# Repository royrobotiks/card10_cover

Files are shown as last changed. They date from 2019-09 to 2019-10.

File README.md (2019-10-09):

# A cover generator for the CARD10 badge!
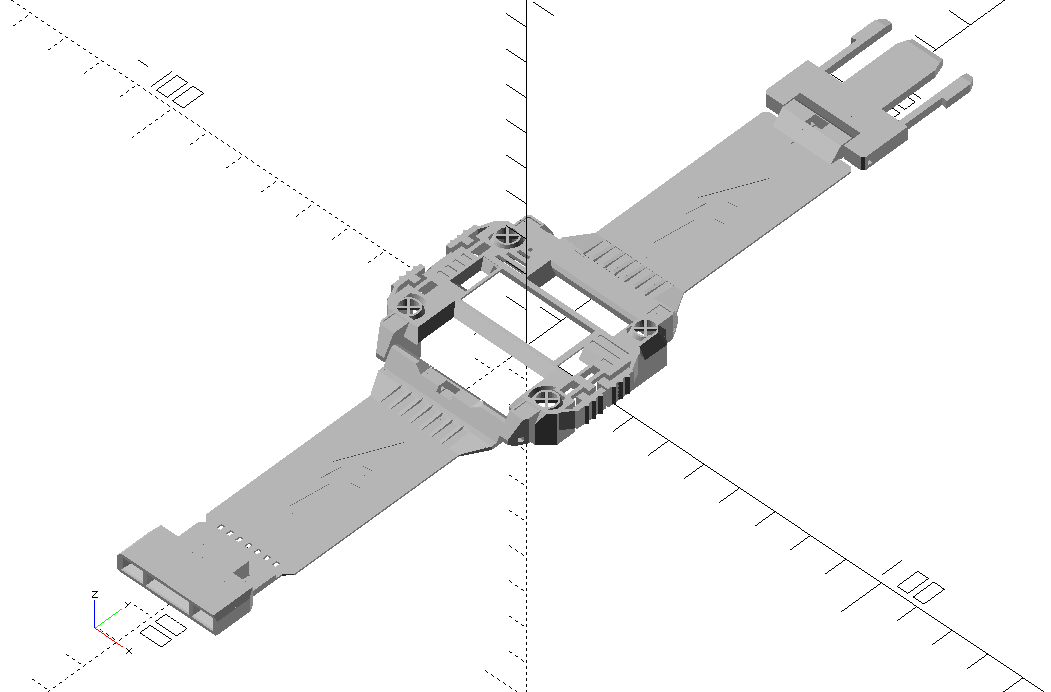
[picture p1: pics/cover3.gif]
different covers
 
          
## Features
- interactive web interface available at https://card10-cover.0x1b.de/index.php (thx to segal!)
- more variations possible than you'll ever need!!!
- buttons become much more usable as they get a bigger surface
- the cover can be clipped onto the badge - there are no tools required to change the cover
- you can add a piece of clear plastic (e.g. cutout from a cheese packaging) as display protection 
- the model has no overhangs, thus it is very easy to print (except if you turn side led's on)
- you can turn off the randomization and generate exactly the cover that YOU want!

## How to use
- open this code in openSCAD (download from https://www.openscad.org/)
- specify whether you want a model with wristband or without (line 82) / the option
          with wristband also adds the wristband mounts (32 mm) to the watch cover
- if you want to print a wristband, specify the sircumference of your wrist in line 107
- specify from line 69 on which parts you want to generate 
- select in line 68 if you want to have the parts oriented ready for print or in the way they will be
          assembled later
- [optional]: adjust settings below in the section 'CUSTOMIZE YOUR COVER BY ADJUSTING VALUES BELOW:'
- hit the render button in openSCAD (the button above the code with the hourglass & the cube)
- hit the .stl export button right next to the render button
- print your .stl model!

## Printing instructions

- print upside down without support out of PLA
- recommended slicer settings: 
   0.2mm layer height
   0.4mm wall thickness / 1 wall
   100% infill 
   0.4mm extruder

## Assembly instructions

- clean up the print with a small utility knife
- [optional]: cut a 14mm x 30mm piece of clear plastic as display protection (e.g. from a pet-bottle) 
                      and place it inside the display cutout 
- If you printed a wristband: Glue FClip on the end of the bottom wristband (e.g. with superglue)
- connect MClip with the top wristband (with a paper clip as axle)
- connect both wristbands to the cover (with paper clips as axles)
- if you printed a bottom: Unscrew the four screws on the bottom of the Card10, 
          remove the stainless steel electrodes, add the bottom piece, add the electrodes, 
          add the screws again.
- clip the cover onto your card10 badge
- print another cover for your friends

## Wristband assembly

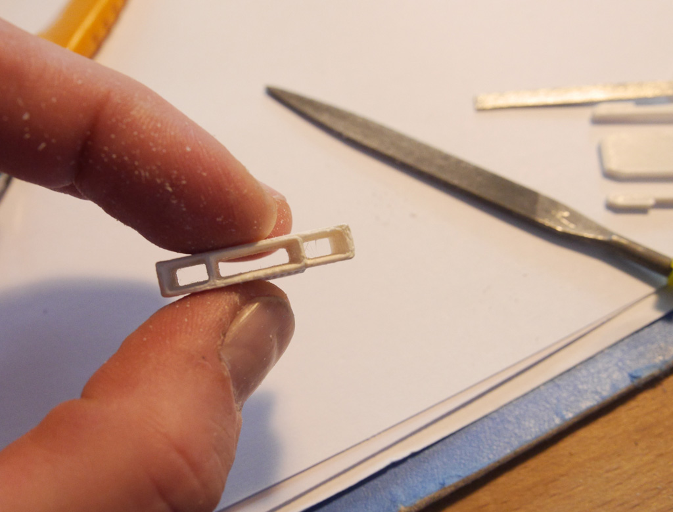
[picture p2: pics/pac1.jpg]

Step 1: Clean up the inside of FClip with a small file.

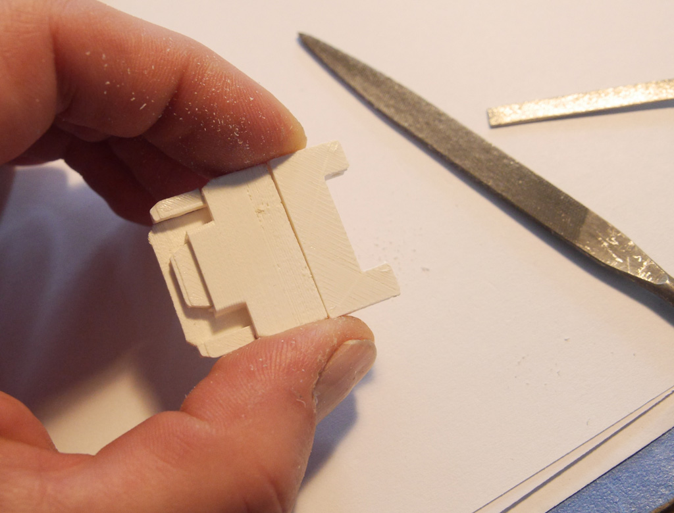
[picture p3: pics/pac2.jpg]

Step 2: Make sure that MClip fits smooth into FClip.

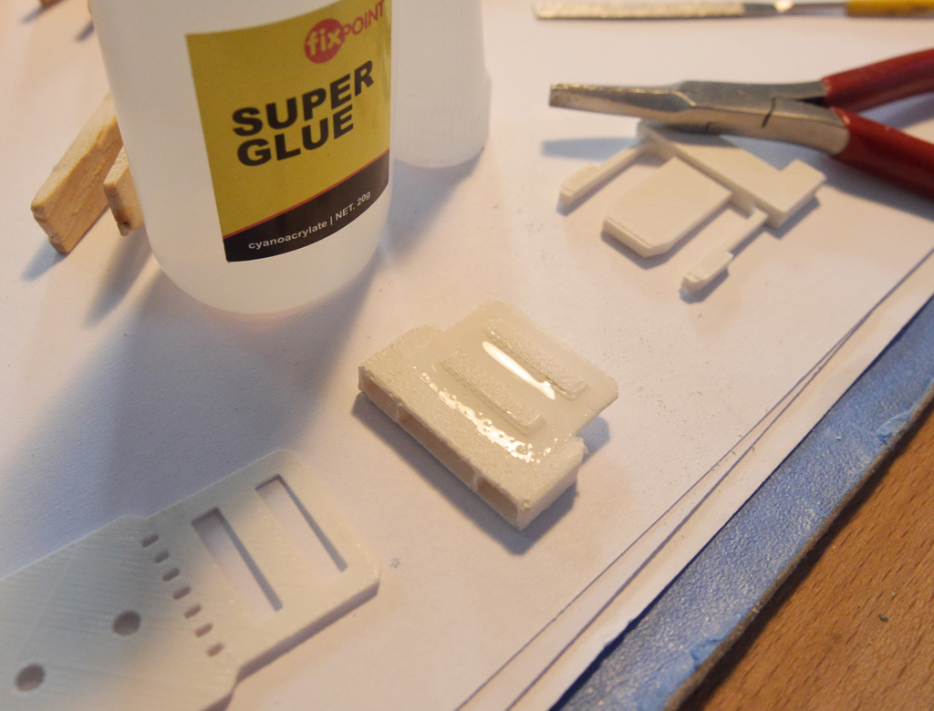
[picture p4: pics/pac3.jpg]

Step 3: Glue FClip onto the bottom piece of the wristband. 

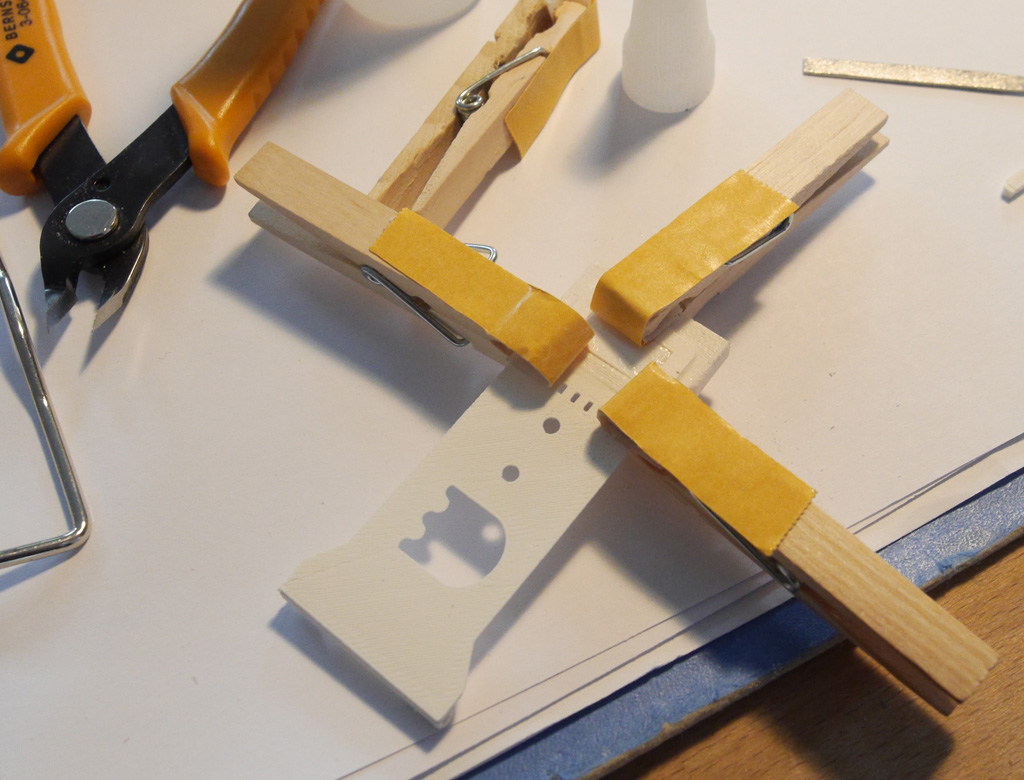
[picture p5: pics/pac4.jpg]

Pro-tip: Clothespins are nice for clamping the pieces together while the glue cures. A piece of tape (e.g. electric tape or the yellow back-foil on double sided tesa tape prevents the superglue to bond with the clothespins).

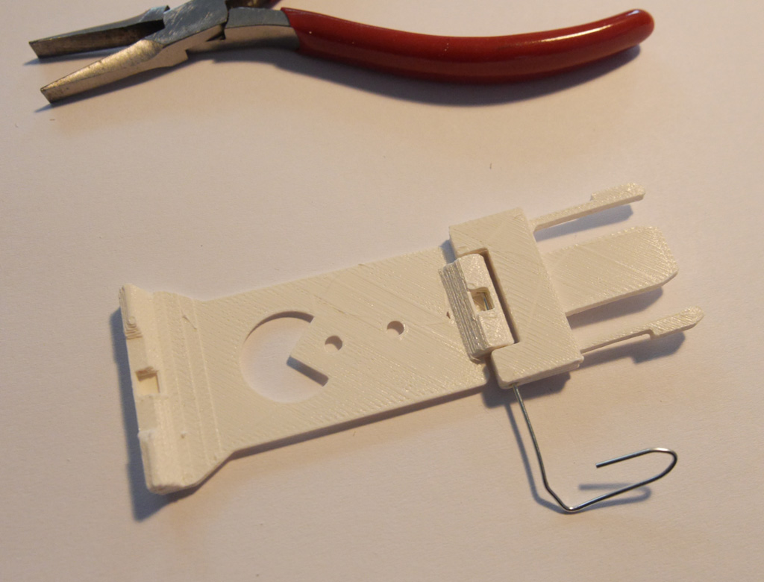
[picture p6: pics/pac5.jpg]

Step 4: Connect MClip and the top part of the wristband with a paperclip. Cut the paperclip to size.

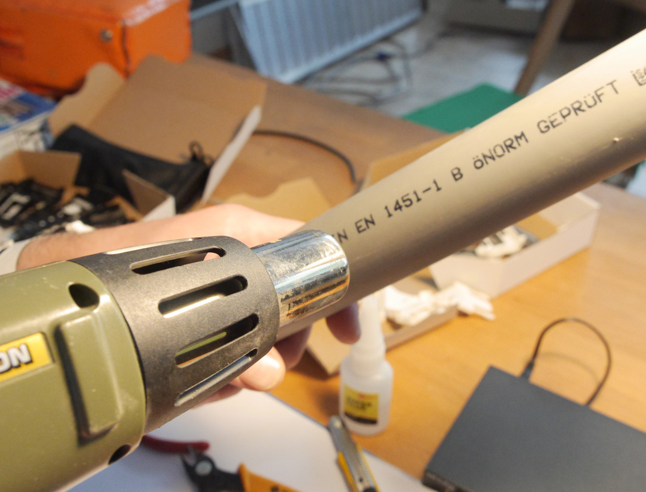
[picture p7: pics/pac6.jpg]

Step 5: Heat up a piece of pipe with a hot air gun...

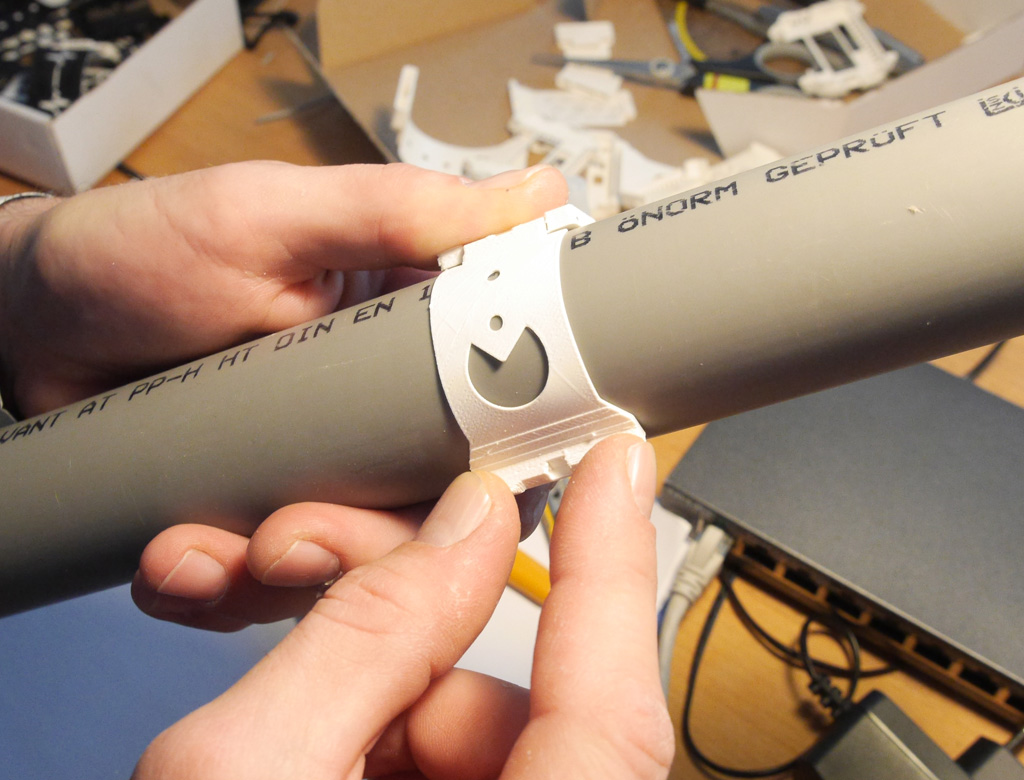
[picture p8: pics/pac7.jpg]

... and use the hot pipe to bend the wristband pieces.

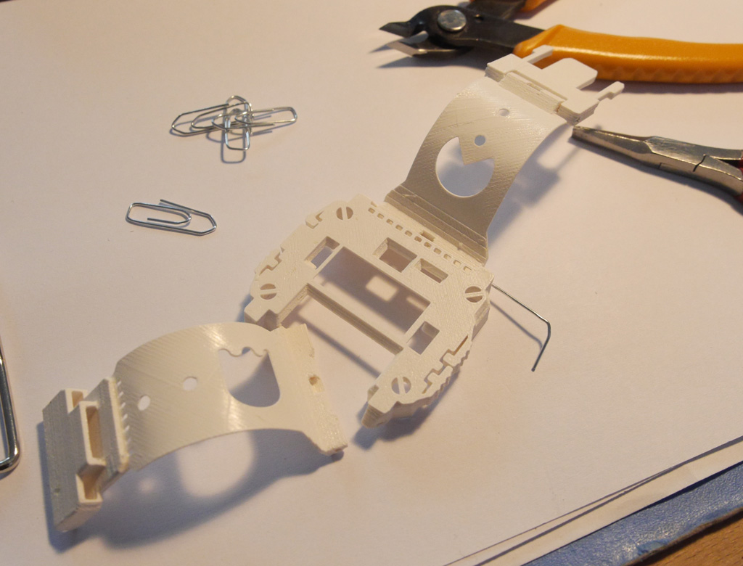
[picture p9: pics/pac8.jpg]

Step 6: Connect the wristband pieces and the cover with paperclips.

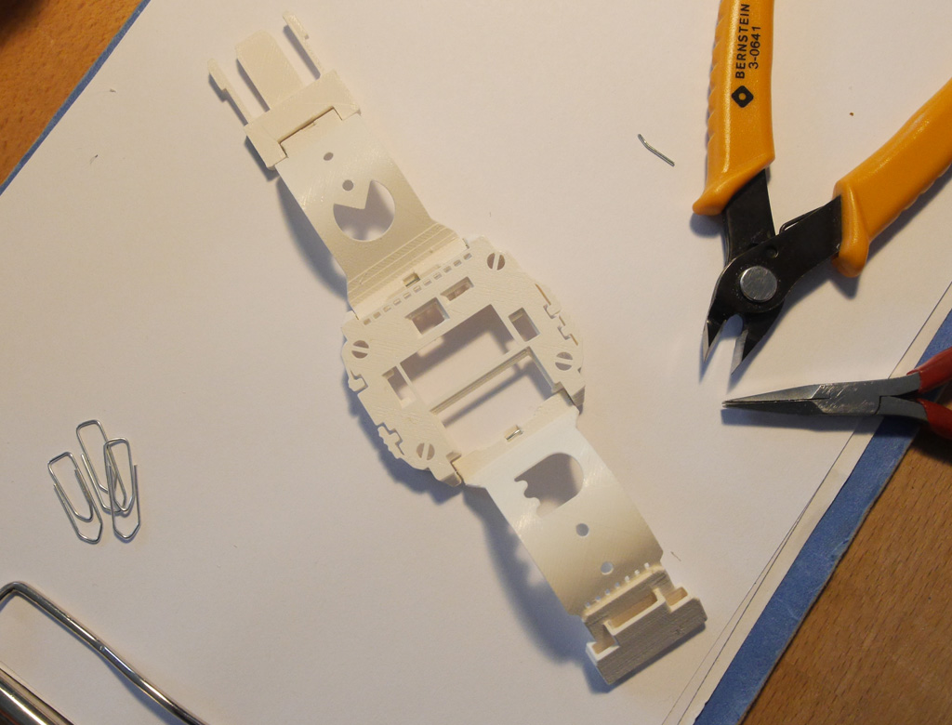
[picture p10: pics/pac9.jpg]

This is the finished clip-on cover! You can also add the bottom plate to your Card10. This would be screwed in between the lower circuit board and the metal electrodes.

## Examples

I added some stl files which were generated with Version 1 & 2 as examples. Here's a print of the model 1337haxx0r with all features unlocked:

card10-model 1337haxx0r

All of the models feature a recessed display cutout where you can place a 30mm x 14mm transparent plastic piece as display protection.

cover with plastic display protection

Here's the model 'functional style' with half diffusor after losing a round of Tetris:

functional style

And here's a bunch of prints with different features. I cut out pieces from some food packaging for the screen protectors:

different card10 cover prints

Thhere were plenty of test prints involved in making this work out nicely: 

different card10 cover prints

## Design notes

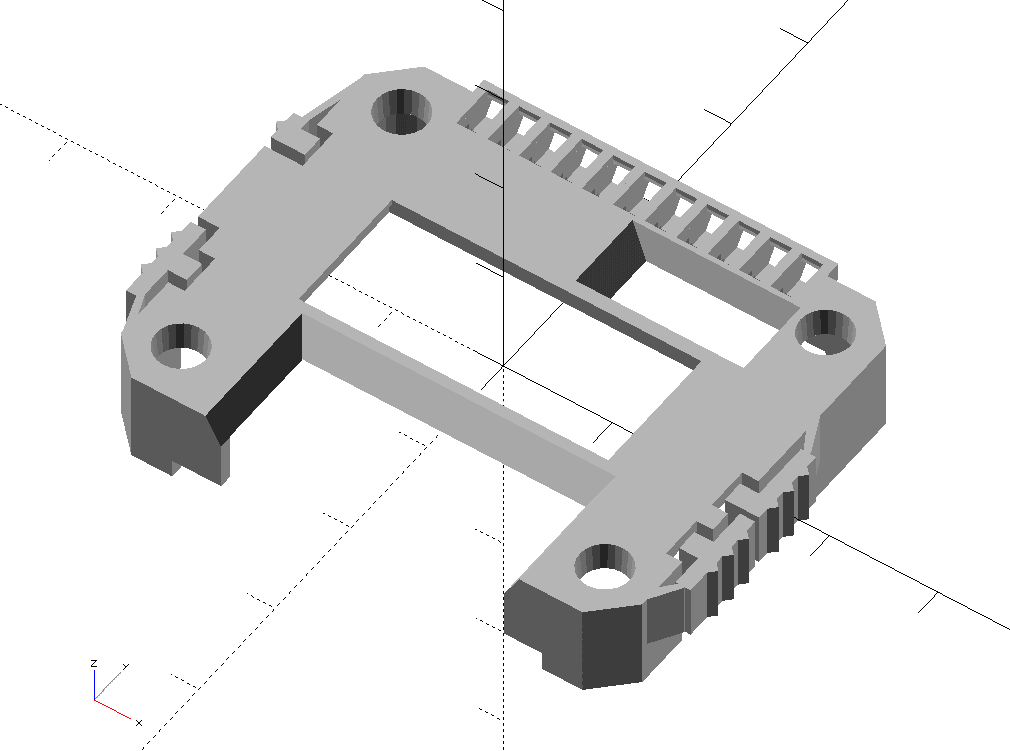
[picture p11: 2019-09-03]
pics/card10_anim.gif

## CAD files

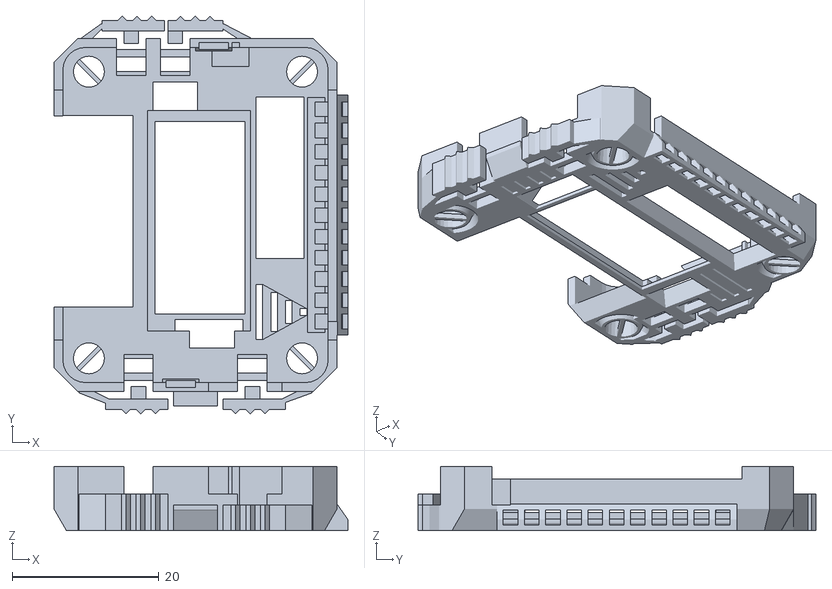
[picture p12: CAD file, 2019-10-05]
stls/BasicCovers/card10_basic_5.stl
40.0 x 54.1 x 8.75

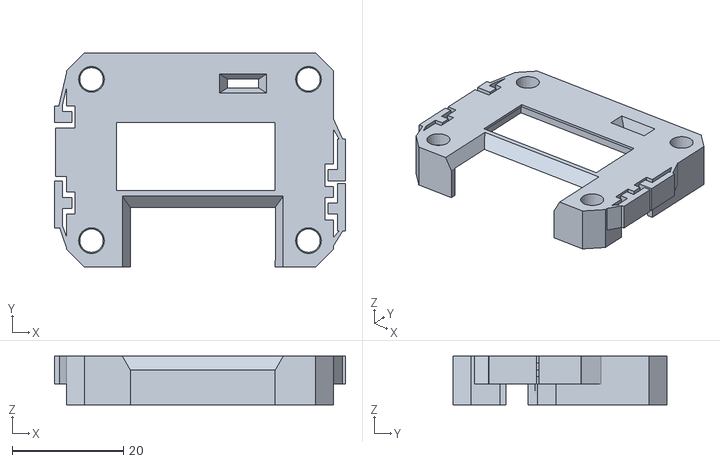
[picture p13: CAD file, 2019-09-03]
stls/card10_cover_elegant_look.stl
52.3 x 38.5 x 8.75

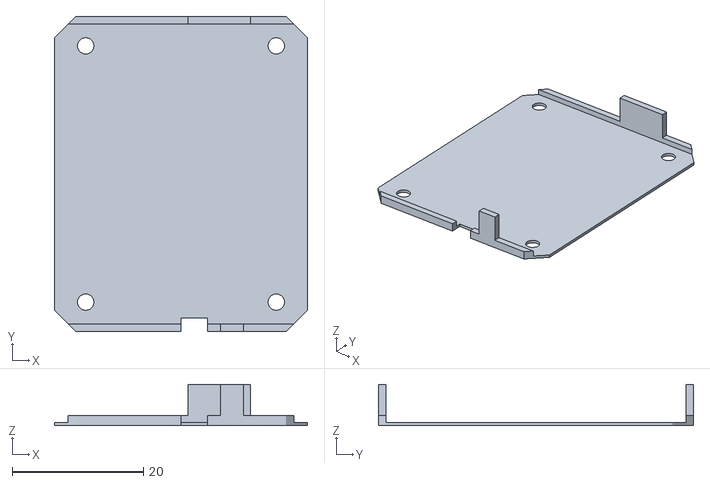
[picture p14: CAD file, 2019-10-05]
stls/Extras/card10_bottom_plate.stl
38.5 x 48.0 x 6.25

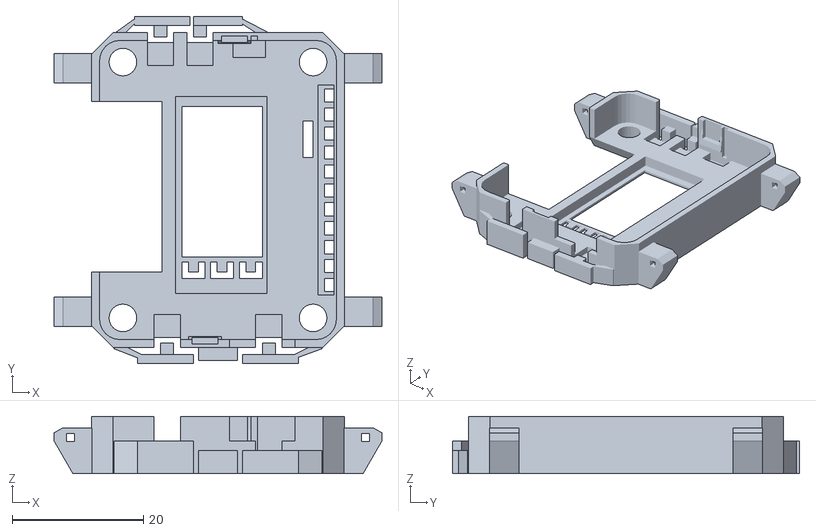
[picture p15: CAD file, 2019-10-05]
stls/WristbandCovers/card10_WristbandCover_4.stl
50.0 x 52.9 x 8.75

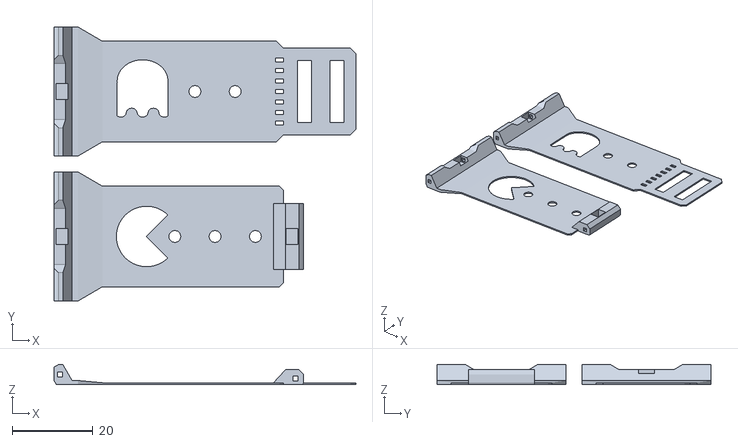
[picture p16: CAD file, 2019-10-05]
stls/WristbandParts/180mm_pacman.stl
75.0 x 68.0 x 5.00

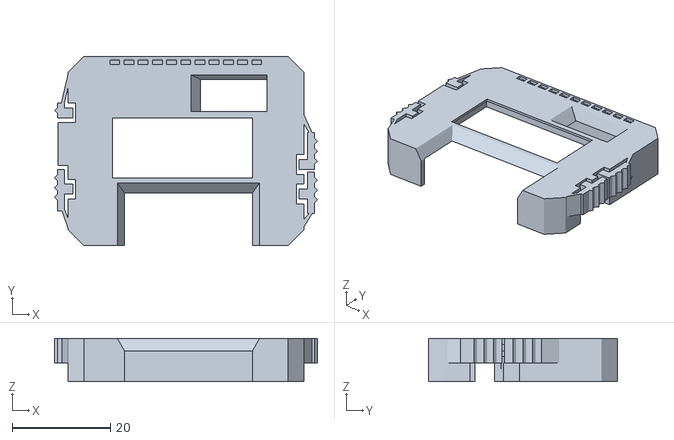
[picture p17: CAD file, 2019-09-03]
stls/card10_cover_functional_style.stl
53.5 x 38.5 x 8.75

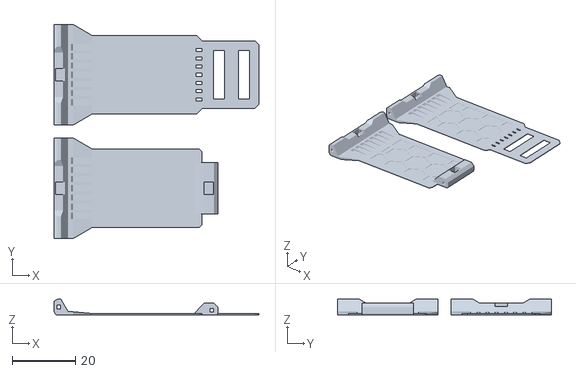
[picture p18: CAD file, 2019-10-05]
stls/WristbandParts/160mm_hexstructure.stl
65.0 x 68.0 x 5.00

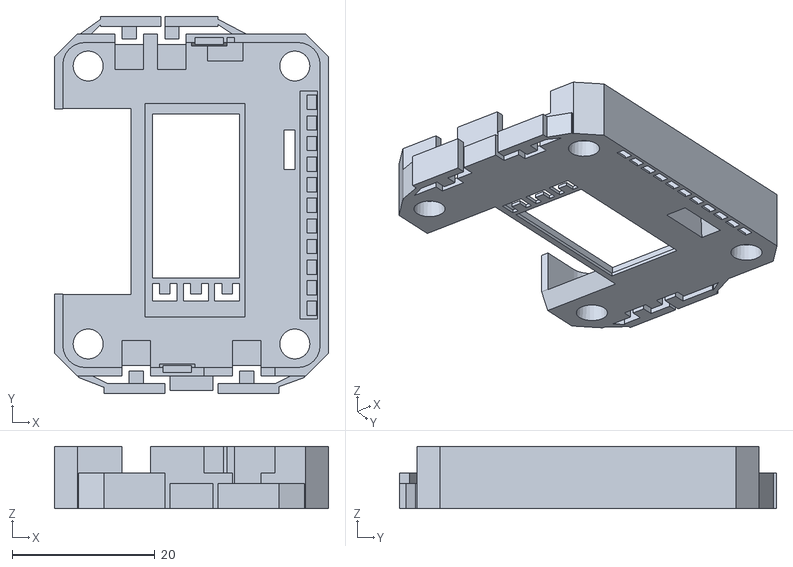
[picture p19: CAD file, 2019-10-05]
stls/BasicCovers/card10_basic_2.stl
38.5 x 52.9 x 8.75

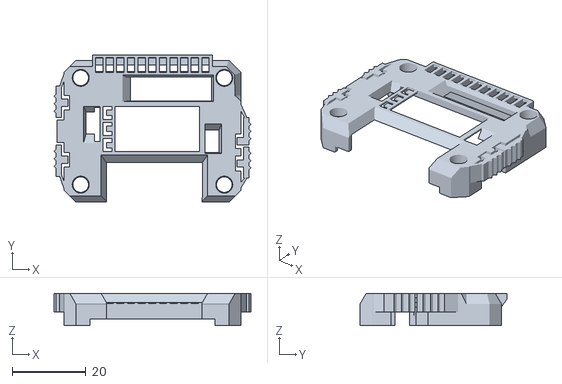
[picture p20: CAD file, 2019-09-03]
stls/card10_cover_1337_haxxor.stl
53.5 x 40.0 x 8.75

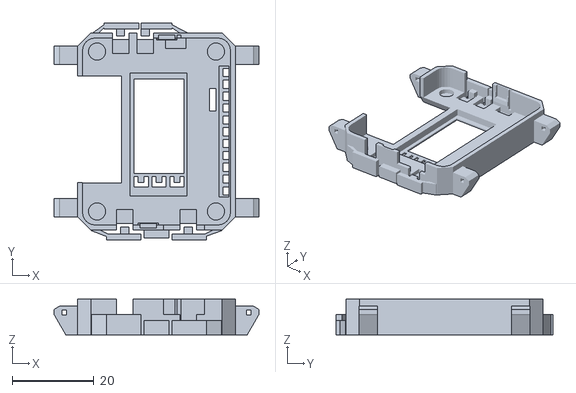
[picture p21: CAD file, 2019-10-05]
stls/WristbandCovers/card10_WristbandCover_3.stl
50.0 x 52.9 x 8.75

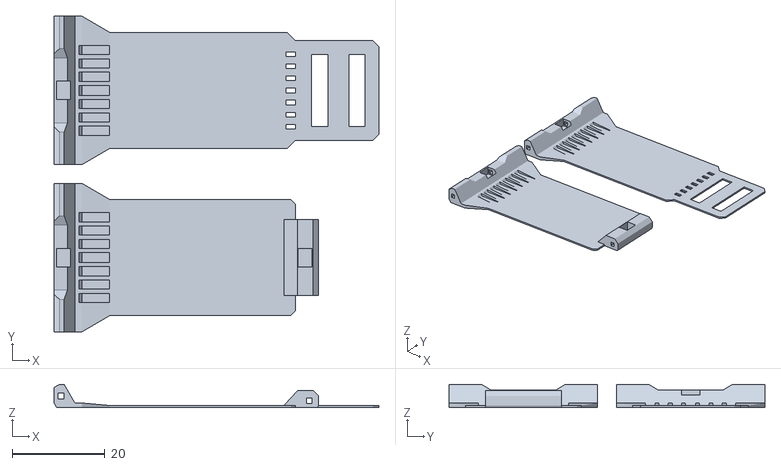
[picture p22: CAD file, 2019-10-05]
stls/WristbandParts/170mm_plain.stl
70.0 x 68.0 x 5.00

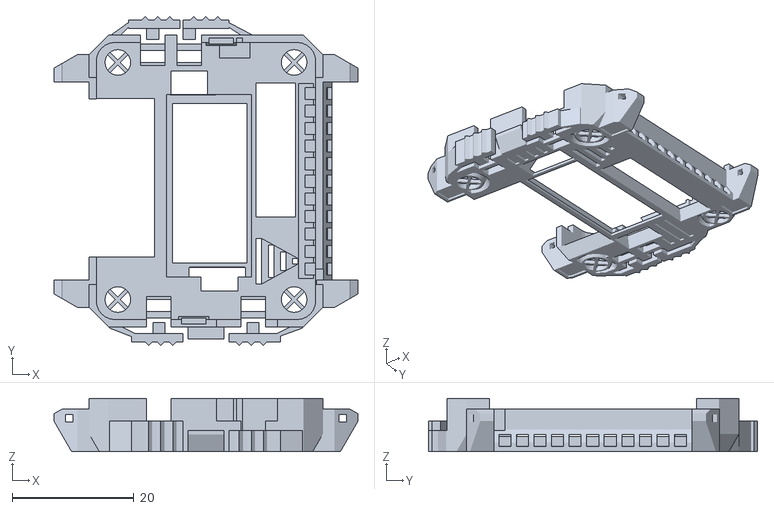
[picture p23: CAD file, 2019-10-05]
stls/WristbandCovers/card10_WristbandCover_1.stl
50.0 x 54.1 x 8.75

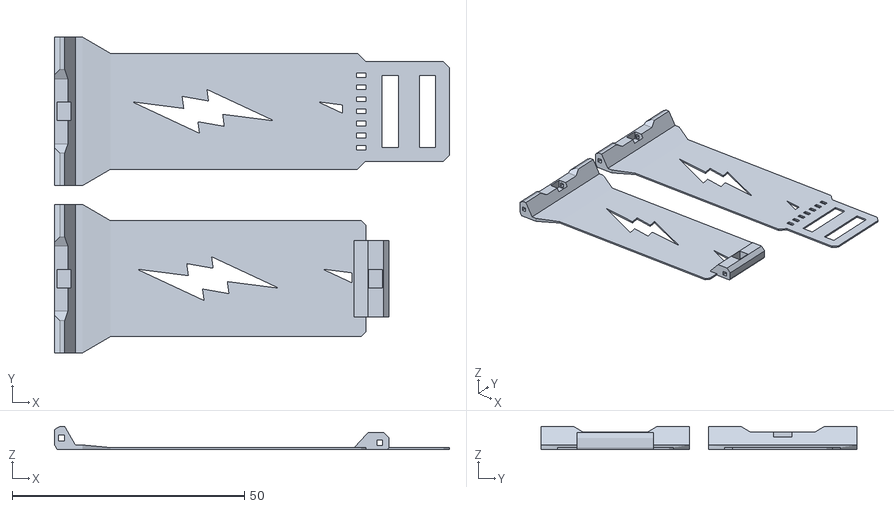
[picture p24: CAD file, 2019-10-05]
stls/WristbandParts/200mm_flash.stl
85.0 x 68.0 x 5.00

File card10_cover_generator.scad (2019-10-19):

/*
          
          A random cover generator for the CARD10 badge!
          ==============================================
          
          V3.2
          
          Cover features:
          ---------------
        * more variations possible than you'll ever need!!!
        * buttons become much more usable as they get a bigger surface
        * the cover can be clipped onto the badge - there are no tools required to change the cover
        * you can add a piece of clear plastic (e.g. cutout from a cheese packaging) as display protection 
        * the model has no overhangs, thus it is very easy to print (except if you turn side led's on)
        * you can turn off the randomization and generate exactly the cover that YOU want!
        
        
          How to use:
          -----------
        * open this code in openSCAD (download from https://www.openscad.org/)
        * specify whether you want a model with wristband or without (line 82) / the option
          with wristband also adds the wristband mounts to the watch cover
        * if you want to print a wristband, specify the sircumference of your wrist in line 107
        * specify from line 69 on which parts you want to generate 
        * select in line 68 if you want to have the parts oriented ready for print or in the way they will be
          assembled later
        * [optional]: adjust settings below in the section 'CUSTOMIZE YOUR COVER BY ADJUSTING VALUES BELOW:'
        * hit the render button in openSCAD (the button above the code with the hourglass & the cube)
        * hit the .stl export button right next to the render button
        * print your .stl model!
        
        
          Printing instructions on an FDM printer:
          ----------------------------------------
        * print upside down without support out of PLA
        * recommended slicer settings: 
            0.2mm layer height
            0.4mm wall thickness / 1 wall
            100% infill 
            0.4mm extruder
  
  
          Assembly instructions:
          ----------------------
        * clean up the print with a small utility knife
        * [optional]: cut a 14mm x 30mm piece of clear plastic as display protection (e.g. from a pet-bottle) 
                      and place it inside the display cutout 
        * If you printed a wristband: Glue FClip on the end of the bottom wristband (e.g. with superglue)
        * connect MClip with the top wristband (with a paper clip as axle)
        * connect both wristbands to the cover (with paper clips as axles)
        * if you printed a bottom: Unscrew the four screws on the bottom of the Card10, 
          remove the stainless steel electrodes, add the bottom piece, add the electrodes, 
          add the screws again.
        * clip the cover onto your card10 badge
        * print another cover for your friends
          
  
          License:
          ----------------------------------------------------------------------------
          "THE TSCHUNK-WARE LICENSE" (Revision 23):
          Niklas Roy wrote this file. As long as you retain this notice you
          can do whatever you want with this stuff. If we meet some day, and you think
          this stuff is worth it, you can buy me a tschunk in return
          ----------------------------------------------------------------------------
*/
echo("///////////////  CARD10 COVER GENERATOR  ///////////////");

//generate random seed number for all random generators

rndSeed=round(rands(0,5000,1)[0]); 

echo("Generating cover #");
echo(rndSeed);

none=0;half=1;full=2;normal=0;tiny=1;hidden=1;
visible=2;protected=3;protectedX=4;
wide=32;standard=25;
plain=0;  hexagons=1; pacman=2; heartbeat=3; flash=4;
function maybe()=round(rands(0,1,1,seed_value=rndSeed)[0])==1;
function rnd(x) =round(rands(0,x,1,seed_value=rndSeed)[0]);

//////////////////////////////////////////////////////////

// display all parts either in optimized print orientation 
// [ideal for exporting stl's for fdm prints] or in assembly view

// %% 'Print view' bool false 
printOrientation=false;

// select which parts you want to generate
// %% 'Generate watch cover' bool true 
generateCover       = true;
// %% 'Generate bottom plate' bool false 
generateBottom      = true;
// %% 'Generate wristband top' bool true 
generateBeltTop     = true;
// %% 'Generate wristband bottom' bool true 
generateBeltBottom  = true;
// %% 'Generate F clip' bool true 
generateFClip       = true; 
// %% 'Generate M clip' bool true 
generateMClip       = true;



// ***********************************************
// CUSTOMIZE YOUR COVER BY ADJUSTING VALUES BELOW:
// ***********************************************

// do you want to connect a 3D-printed wristband to your case? // this toggles the belt mounts on the case
// %% 'Generate wristband' bool true 
wristBand           = true;

// wrist band width - options are 'standard' and 'wide'
// %% 'Wristband width' select (25='Standard',32='Wide') 
beltWidth           =  standard; 

// plain', 'pacman', 'hexagons', 'heartbeat', 'flash'
// %% 'Wristband style' select (0='Plain',1='Hexagons',2='Pacman',3='Heartbeat',4='Flash') 
beltStyle           = rnd(4);//flash;


//circumference of the wrist in mm
// %% 'Wrist circumference' int (min=140,max=250,default=190)
wristCircumference  = 190;

// adjust diffusion layer above leds - options are:
// 'full' [full diffusion - led's are invisible when turned off]
// 'half' [only diffusion at bottom ...
//           ... led's won't blind you when you look at the display]
// 'none' [led's remain fully open - you get top brightness!]
// %% 'LED diffusor' select (0='None',1='Half',2='Full')
ledDiffusor         = rnd(2);//half;  

// toggle sideways visibility of top row led's 
// - if set to 'true', you'll have to print with minimal overhangs!
// %% 'LED top side cutout' bool true 
sideLEDs            = maybe();//true; 

// add protruding led protector on top
// %% 'Extended LED bar' bool true 
extendedLEDs        = maybe();//true;

// toggle cutout for visibility of personal state led
// %% 'Personal State LED visibility' bool true 
personalStateLED    = maybe();//true;  

// toggle visibility of left led rocket
// %% 'Left rocket visibility' bool true 
showLeftRocket      = maybe();//false;

// toggle visibility of right led rocket
// %% 'Right rocket visibility' bool true 
showRightRocket     = maybe();//true;  

// toggle visibility of top led rocket
// %% 'Top rocket visibility' bool true 
showTopRocket       = maybe();//false;  

// toggle cutout for sewable connectors
// %% 'GPIO accessibility' bool true 
GPIOaccess          = maybe();//true;  

// toggle bevels - [no bevels make the cover look more blocky]
// %% 'Bevels' bool true 
bevels              = maybe();//false; 

// toggle size of on-off-home button. options are:
// - 'normal' [explains itself]
// - 'tiny'   [tiny button in order to avoid accidental turn-off]

// %% 'Home button cover' select (0='Normal',1='Tiny') 
homeButtonCover     = normal;  

// toggle whether buttons have a riffled surface 
// - otherwise button surface is flat
// %% 'Riffled buttons' bool true 
riffledButtons      = maybe();//true;  

// cut out a small rectangle above the physical button in order to 
// make silver button case visible. blingbling!
// %% 'Shiny button cutouts' bool true 
shinyButtons        = maybe();//false;

// show more of the display module than just the screen area
// - when false, ccc is shown on the left side of the screen area
// %% 'Large screen cutout' bool true 
largeScreen         = maybe();//false;  

// toggle visibility of CARD10 logo   
// %% 'Logo visibility' bool true    
showLogo            = maybe();//false;  

// set screw style. options are 'hidden', 'visible', 'protected' or 'protectedX'
// %% 'Wristband style' select (1='Hidden',2='Visible',3='Protected',4='X-Protected') 
screwStyle          = rnd(3)+1;//protected; 

// embossed rings around screws?
// %% 'Screw visibility' bool true 
screwRings          = maybe();//false; 

// a little useless grill on top of the spikes???
// %% 'Useless grill' bool true 
spikeGrill          = maybe();//true;

//make multicolor prints by changing the filament after the first layer was printed - can be also just set to true if you want to have a bit more texture in the first layer
// %% 'First layer texture' bool true 
firstLayerDeco=maybe();//;
    
// END OF CUSTOMIZATION!

//////////////////////////////////////////////////////////
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

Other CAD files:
stls/BasicCovers/card10_basic_1.stl
stls/BasicCovers/card10_basic_4.stl
stls/WristbandCovers/card10_WristbandCover_5.stl
stls/WristbandParts/190mm_heartbeat.stl
stls/WristbandParts/FClip.stl
stls/WristbandParts/MClip.stl

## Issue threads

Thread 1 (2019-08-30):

Add recesses for the 3 rocket Leds

christian-draeger, 2019-08-30:
Could someone who is familiar with adjusting the model please add recesses for the three rocket leds that are shining through the harmonic board?
So the case would not cover any of the sensors and leds from card10. Maybe also with adjustable led diffusion thickness like for the row of leds on top.
Would try to print it with "transparent" pla and put a small plate of thin glass in the display cutout (fixed with glue)

royrobotiks, 2019-08-30:
Hi Christian,
you can adjust the led diffusion layer thickness for the 11 led's on top already. Just change the value in line 28 of the OpenSCAD code: ledDiffusionThickness=.28;
Did I miss any cutouts for sensors? I understood that there's only the IR photo sensor below the 11 leds and the ecg+blood oximeter, which are both not covered. But yes, I covered the rocket led's and there could be cutouts, too. Those could be included e.g. as "cubes" between the lines 78 & 80.

christian-draeger, 2019-08-30:
Thx for the fast response.
Yeah i mean the 3 rocket leds. Imho a solution simular to the led row on top (variant thickness) would be very nice. Since i have absolutely no clue regarding creatibg or adjusting 3d models it would ve awesome if someone more experienced could adjust the model

royrobotiks, 2019-09-03:
Hi Christian, I refined the scad file. Now it's generative and you can print a model with the features that you requested :)

Closed 2019-09-03.

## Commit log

2019-09-03 Add files via upload
    An example of a generative card10 cover with all features unlocked
    [card10_cover_1337_haxxor.stl]
2019-09-03 Add files via upload
    A new simple card10 cover with minimal features - in case you want to look elegant
    [card10_cover_minimal_look.stl]
2019-09-03 Add files via upload
    A generative card10 cover with emphasis on functionality - no blinding top led's and access to the most important harmonic board features
    [card10_cover_functional_style.stl]
2019-09-03 Add files via upload
    A card10 cover generator - make the cover that you want!
    [card10_cover_generator.scad]
2019-09-04 Add files via upload
    some more prints
2019-09-04 Add files via upload
    test prints
2019-10-04 Version 3.0 of the Card10 Cover Generator
    New version includes wristbands and even more options!
    [card10_cover_generator.scad]
2019-10-04 random seed update + tagging
    Every random generated model gets a number and can be recreated by using this number as rnd seed
    Boolean inputs are tagged for web GUI parsing
    [card10_cover_generator.scad]
2019-10-05 Added 'select' and 'int' tags
    Code has now consistent tagging for integer inputs and single inputs with many options
    [card10_cover_generator.scad]
2019-10-05 Added pictures of wristband assembly
2019-10-05 Added example STL's
    [160mm_hexstructure.stl, 170mm_plain.stl, 180mm_pacman.stl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]
2019-10-19 V3.2
    Bugfix: It's now possible to generate a cover with wrist band mounts without making a wrist band
    [card10_cover_generator.scad]
2019-10-19 V3.2
    changed a value
    [card10_cover_generator.scad]
